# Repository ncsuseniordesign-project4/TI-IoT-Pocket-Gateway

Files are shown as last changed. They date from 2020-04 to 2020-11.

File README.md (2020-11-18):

# TI-IoT-Pocket-Gateway

Please see the [wiki](https://github.com/ncsuseniordesign-project4/TI-IoT-Pocket-Gateway/wiki) as well!

## Hardware

Hardware design files can be found under the `hardware` folder. You will need AutoCAD Eagle to modify these files.

CAM Data:
   The up to day CAM outputs are in the zipped file "IoT_Pocket_Gateway_Final.zip". 

## Software

Demo scripts, testing tools, etc can be found under the `software` folder, including a simple demo web app for communicating with a remote device using the Azure IoT Hub.

## Configuration

A `systemd` service for modem configuration / management can be found under the `configuration` folder. The various demo scripts in the `software` folder also provide examples showing how the buttons and LEDs can be used. Please see the [wiki](https://github.com/ncsuseniordesign-project4/TI-IoT-Pocket-Gateway/wiki) as well!

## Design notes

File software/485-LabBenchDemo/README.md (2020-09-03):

# TI-IoT-Pocket-Gateway

## Dependencies

* bonescript
* azure-iot-device
* azure-iot-device-mqtt

Dependencies can be installed via `npm install <dependency_name>`. Note that `bonescript` is install by default on the PocketBeagle and does not need to be reinstalled.

## Cloud9 IDE QuickStart
The PocketBeagle must have an exsiting network connection.

First, clone this repo to a new subfolder of `/var/lib/cloud9` on the PocketBeagle. Next, start up Cloud9 in your web browser. In the left hand Workspace view a new `TI-IoT-Pocket-Gateway` folder will now be present. Expand this folder as well as the 485-LabBenchDemo folder. The `485-LabBenchDemo.js` file will now be displayed and can be opened by double clicking it. This will open the source code in the IDE.

Now that the file is open switch to the Clound9 terminal. Ensure the project dependencies are installed (see the above dependencies section). Once the dependencies have been installed ensure your IoT Device primary key has been added to the configuration file at `/etc/485-LabBenchDemo.conf`. If no configuration file has yet been created a sample configuration, `485-LabBenchDemo.conf.sample`, has been provided which can be copied to `/etc/485-LabBenchDemo.conf`.

Once the configuration is correct the program can be started via Cloud9's "Run" button. Once started the program will print the messages it receives from Azure and handle defined method calls.

### Cloud9 Autostart

This program can be autostarted by Cloud9 by copying or symlinking it to the `/var/lib/cloud9/autorun` folder. An active network connection is not required to start the program and the program will automatically start sending messages to Azure once a network connection has been made.

## NPM and Node QuickStart
Run the following commands after cloning or after git pull.

First, go to the directory with all the scripts and the package.json file

To install the package dependencies, run the following command:

```
npm install
```

A folder called `node_modules` will be created with all the Azure dependencies

Now, edit `/etc/485-LabBenchDemo.conf` to provide the program with your IoT Device primary key. A sample config, `485-LabBenchDemo.conf.sample`, has been provided so the configuration file does not need to be created from scratch.

Run the script with node command:

```
node [script-of-your-choice].js
```

The data will be sent to the IoT device specified by the connectionString in JSON format.

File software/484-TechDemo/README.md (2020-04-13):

# TI-IoT-Pocket-Gateway

## Dependencies

* bonescript
* azure-iot-device
* azure-iot-device-mqtt

Dependencies can be installed via `npm install <dependency_name>`. Note that `bonescript` is install by default on the PocketBeagle and does not need to be reinstalled.

## Cloud9 IDE QuickStart
The PocketBeagle must have an exsiting network connection.

First, clone this repo to a new subfolder of `/var/lib/cloud9` on the PocketBeagle. Next, start up Cloud9 in your web browser. In the left hand Workspace view a new `TI-IoT-Pocket-Gateway` folder will now be present. Expand this folder as well as the 484-TechDemo folder. The `484-TechDemo.js` file will now be displayed and can be opend by double clicking it. This will open the source code in the IDE.

Now that the file is open switch to the Clound9 terminal. Ensure the project dependencies are installed (see the above dependencies section). Once the dependencies have been installed ensure your IoT Device primary key has been added to the configuration file at `/etc/484-TechDemo.conf`. If no configuration file has yet been created a sample configuration, `484-TechDemo.conf.sample`, has been provided which can be copied to `/etc/484-TechDemo.conf`.

Once the configuration is correct the program can be started via Cloud9's "Run" button. Once started the program will print the messages it sends to Azure to the log and the RGB LED will be controllable by moving the TechLab around.

### Cloud9 Autostart

This program can be autostarted by Cloud9 by copying or symlinking it to the `/var/lib/cloud9/autorun` folder. An active network connection is not required to start the program and the program will automatically start sending messages to Azure once a network connection has been made.

## NPM and Node QuickStart
Run the following commands after cloning or after git pull.

First, go to the directory with all the scripts and the package.json file

To install the package dependencies, run the following command:

```
npm install
```

A folder called `node_modules` will be created with all the Azure dependencies

Now, edit `/etc/484-TechDemo.conf` to provide the program with your IoT Device primary key. A sample config, `484-TechDemo.conf.sample`, has been provided so the configuration file does not need to be created from scratch.

Run the script with node command:

```
node [script-of-your-choice].js
```

The data will be sent to the IoT device specified by the connectionString in JSON format.

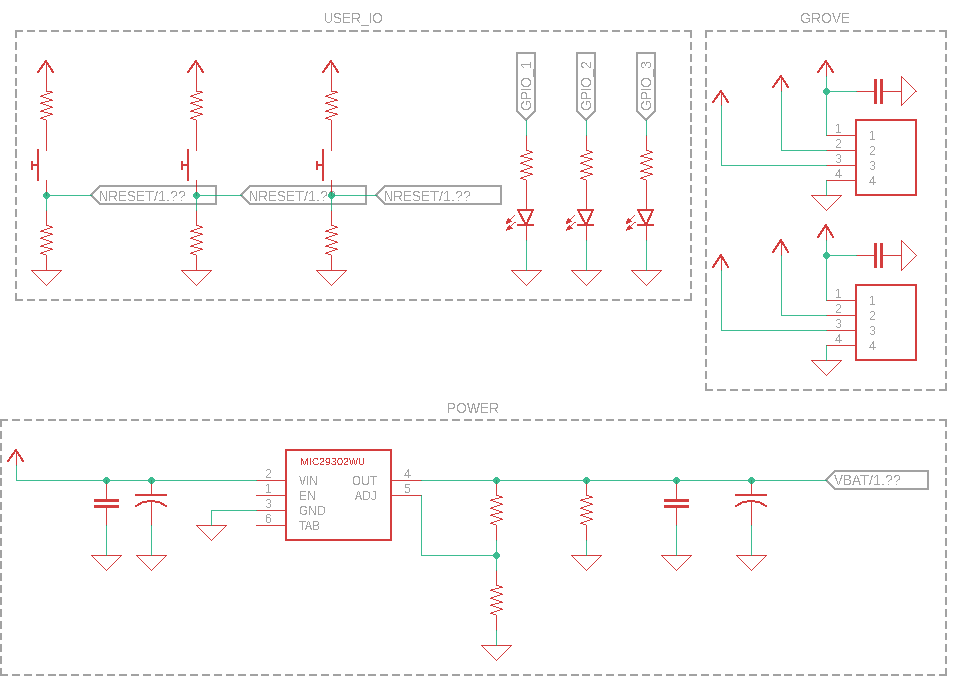
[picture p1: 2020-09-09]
hardware/Eagle/Sheet 2 Update.png

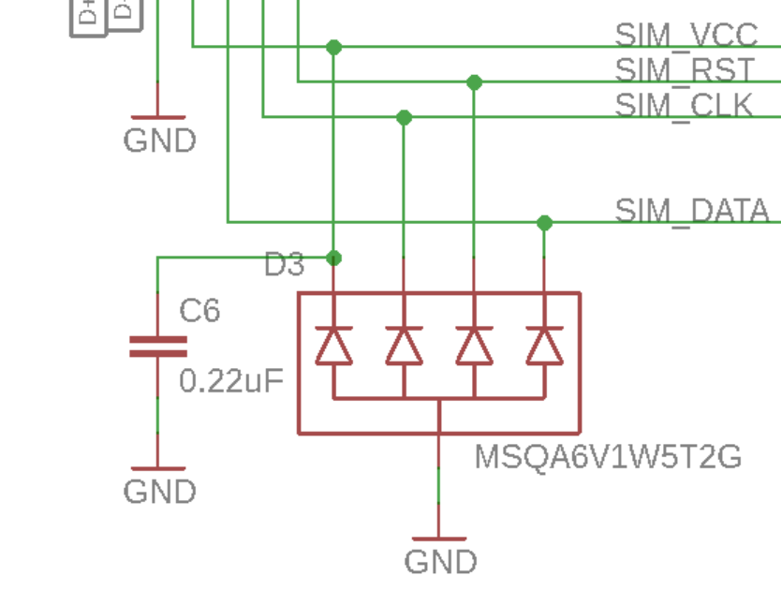
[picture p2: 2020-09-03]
hardware/Eagle/Sim 3.3v ESD diode.png

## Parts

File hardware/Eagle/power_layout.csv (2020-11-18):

Part | Value | Device | Package | Description | AVAILABILITY | BUILT_BY | CENTERLINE_PITCH | COMMENT | COPYRIGHT | DATASHEET | DESCRIPTION | DIGI-KEY_PART_NUMBER | DIGI-KEY_PURCHASE_URL | EU_ROHS_COMPLIANCE | MANUFACTURER | MANUFACTURER_PART_NUMBER | MF | MP | MPN | NUMBER_OF_POSITIONS | OC_FARNELL | OC_NEWARK | PACKAGE | POPULARITY | PRICE | PRODUCT_TYPE | PROD_ID | SOURCELIBRARY | SPICEPREFIX | TE_PURCHASE_URL | TP_SIGNAL_NAME | VALUE | VENDOR
BTN2 | PTS636SM25F | PTS636SM25F | SW2_PTS636_SM25F_SMTR_LFS_CNK
BTN3 | PTS636SM25F | PTS636SM25F | SW2_PTS636_SM25F_SMTR_LFS_CNK
C1 | 100uF | C-USC0805 | C0805 | CAPACITOR, American symbol |  |  |  |  |  |  |  |  |  |  |  |  |  |  |  |  |  |  |  | 63 |  |  |  |  | C
C2 | 0.1uF | C-USC0805 | C0805 | CAPACITOR, American symbol |  |  |  |  |  |  |  |  |  |  |  |  |  |  |  |  |  |  |  | 63 |  |  |  |  | C
C3 | 330uF | C-USC1210 | C1210 | CAPACITOR, American symbol |  |  |  |  |  |  |  |  |  |  |  |  |  |  |  |  |  |  |  | 6 |  |  |  |  | C
C4 | 1uF | C-USC0805 | C0805 | CAPACITOR, American symbol |  |  |  |  |  |  |  |  |  |  |  |  |  |  |  |  |  |  |  | 63 |  |  |  |  | C
C5 | 100nF | C-USC0805 | C0805 | CAPACITOR, American symbol |  |  |  |  |  |  |  |  |  |  |  |  |  |  |  |  |  |  |  | 63 |  |  |  |  | C
C6 | .1uF | C-USC0805 | C0805 | CAPACITOR, American symbol |  |  |  |  |  |  |  |  |  |  |  |  |  |  |  |  |  |  |  | 63 |  |  |  |  | C
C7 | 0.1uF | C-USC0805 | C0805 | CAPACITOR, American symbol |  |  |  |  |  |  |  |  |  |  |  |  |  |  |  |  |  |  |  | 63 |  |  |  |  | C
C8 | .1uF | C-USC0805 | C0805 | CAPACITOR, American symbol |  |  |  |  |  |  |  |  |  |  |  |  |  |  |  |  |  |  |  | 63 |  |  |  |  | C
C9 | .1uF | C-USC0805 | C0805 | CAPACITOR, American symbol |  |  |  |  |  |  |  |  |  |  |  |  |  |  |  |  |  |  |  | 63 |  |  |  |  | C
C10 | .1uF | C-USC0805 | C0805 | CAPACITOR, American symbol |  |  |  |  |  |  |  |  |  |  |  |  |  |  |  |  |  |  |  | 63 |  |  |  |  | C
C11 | .1uF | C-USC0805 | C0805 | CAPACITOR, American symbol |  |  |  |  |  |  |  |  |  |  |  |  |  |  |  |  |  |  |  | 63 |  |  |  |  | C
C12 | 27pF | C-USC0603 | C0603 | CAPACITOR, American symbol |  |  |  |  |  |  |  |  |  |  |  |  |  |  |  |  |  |  |  | 37 |  |  |  |  | C
C13 | 27pF | C-USC0603 | C0603 | CAPACITOR, American symbol |  |  |  |  |  |  |  |  |  |  |  |  |  |  |  |  |  |  |  | 37 |  |  |  |  | C
C14 | 27pF | C-USC0603 | C0603 | CAPACITOR, American symbol |  |  |  |  |  |  |  |  |  |  |  |  |  |  |  |  |  |  |  | 37 |  |  |  |  | C
C15 | 27pF | C-USC0603 | C0603 | CAPACITOR, American symbol |  |  |  |  |  |  |  |  |  |  |  |  |  |  |  |  |  |  |  | 37 |  |  |  |  | C
C16 | 33pF | C-EUC0603K | C0603K | CAPACITOR, European symbol |  |  |  |  |  |  |  |  |  |  |  |  |  |  |  |  |  |  |  | 30 |  |  |  |  | C
C17 | 3uF | C-USC0805 | C0805 | CAPACITOR, American symbol |  |  |  |  |  |  |  |  |  |  |  |  |  |  |  |  |  |  |  | 63 |  |  |  |  | C
CR1 | 9C-6.000MAAJ-T | 9C-6.000MAAJ-T | CRYSTAL_TXC_9C_TXC |  |  | EMA_UL_Team |  |  |  |  |  |  |  |  |  | 9C-6.000MAAJ-T |  |  |  |  |  |  |  |  |  |  |  | TXC_2011-01-01_CRYSTAL_9C |  |  |  |  | TXC
CR2 | ESDA6V1-5SC6SOT23-6L_STM-M | ESDA6V1-5SC6SOT23-6L_STM-M | SOT23-6L_STM-M |  |  | EMA_UL_Team |  |  |  |  |  |  |  |  |  | ESDA6V1-5SC6 |  |  |  |  |  |  |  |  |  |  |  | Update_database_2020-10-15 |  |  |  |  | STMicroelectronics
D1 | RED | LED-RED1206 | LED-1206 | Red SMD LED |  |  |  |  |  |  |  |  |  |  |  |  |  |  |  |  |  |  |  |  |  |  | DIO-09912 |  |  |  |  | RED
D2 | GREEN | LED-GREEN1206 | LED-1206 | Green SMD LED |  |  |  |  |  |  |  |  |  |  |  |  |  |  |  |  |  |  |  |  |  |  | DIO-00862 |  |  |  |  | GREEN
D3 | BLUE | LED-BLUE1206 | LED-1206 | Blue SMD LED |  |  |  |  |  |  |  |  |  |  |  |  |  |  |  |  |  |  |  |  |  |  | DIO-09911 |  |  |  |  | BLUE
D4 | Yellow | LED-YELLOW0603 | LED-0603 | Yellow SMD LED |  |  |  |  |  |  |  |  |  |  |  |  |  |  |  |  |  |  |  |  |  |  | DIO-09003 |  |  |  |  | Yellow
D5 | Yellow | LED-YELLOW0603 | LED-0603 | Yellow SMD LED |  |  |  |  |  |  |  |  |  |  |  |  |  |  |  |  |  |  |  |  |  |  | DIO-09003 |  |  |  |  | Yellow
GROVE1 | 640456-4 | 640456-4 | TE_640456-4 | 220P MTA100 HDR ASSY SQ SPCL |  |  | 2.54 mm[.1 in] | 640456-4 |  |  | Header, Friction Lock | MTA-100 | 4 | 250 VAC | Polyester | Tin | Copper Alloy | Tin | A1922-ND | https://www.digikey.com/product-detail/en/te-connectivity-amp-connectors/640456-4/A1922-ND/109006 | Compliant |  |  | TE Connectivity | 640456-4 |  | 4 |  |  | None |  |  | Connector
GROVE2 | 640456-4 | 640456-4 | TE_640456-4 | 220P MTA100 HDR ASSY SQ SPCL |  |  | 2.54 mm[.1 in] | 640456-4 |  |  | Header, Friction Lock | MTA-100 | 4 | 250 VAC | Polyester | Tin | Copper Alloy | Tin | A1922-ND | https://www.digikey.com/product-detail/en/te-connectivity-amp-connectors/640456-4/A1922-ND/109006 | Compliant |  |  | TE Connectivity | 640456-4 |  | 4 |  |  | None |  |  | Connector
J1 | AU-Y1008-2 | AU-Y1008-2 | CONN_AU-Y1008-2_ASM |  |  | EMA_Cory |  |  | Copyright (C) 2018 Accelerated Designs. All rights reserved | http://www.assmann-wsw.com/fileadmin/datasheets/ASS_5780_CO.pdf |  |  |  |  |  | AU-Y1008-2 |  |  |  |  |  |  |  |  |  |  |  | Assmann_2020-03-30 |  |  |  |  | Assmann
J2 | U.FL-R-SMT-1(01) | U.FL-R-SMT-1(01) | CONN_-SMT-1(01) |  |  | EMA_Matt |  |  | Copyright (C) 2018 Accelerated Designs. All rights reserved |  |  |  |  |  |  | U.FL-R-SMT-1(01) |  |  |  |  |  |  |  |  |  |  |  | Hirose_12_20_2019 |  |  |  |  | Hirose
J3 | U.FL-R-SMT-1(01) | U.FL-R-SMT-1(01) | CONN_-SMT-1(01) |  |  | EMA_Matt |  |  | Copyright (C) 2018 Accelerated Designs. All rights reserved |  |  |  |  |  |  | U.FL-R-SMT-1(01) |  |  |  |  |  |  |  |  |  |  |  | Hirose_12_20_2019 |  |  |  |  | Hirose
JP1 |  | PINHD-1X2 | 1X02 | PIN HEADER |  |  |  |  |  |  |  |  |  |  |  |  |  |  |  |  |  |  |  | 98
JP2 |  | PINHD-1X2 | 1X02 | PIN HEADER |  |  |  |  |  |  |  |  |  |  |  |  |  |  |  |  |  |  |  | 98
JP3 |  | PINHD-1X1 | 1X01 | PIN HEADER |  |  |  |  |  |  |  |  |  |  |  |  |  |  |  |  |  |  |  | 64
JP4 |  | PINHD-1X1 | 1X01 | PIN HEADER |  |  |  |  |  |  |  |  |  |  |  |  |  |  |  |  |  |  |  | 64
JP5 |  | PINHD-1X1 | 1X01 | PIN HEADER |  |  |  |  |  |  |  |  |  |  |  |  |  |  |  |  |  |  |  | 64
JP6 |  | PINHD-1X2 | 1X02 | PIN HEADER |  |  |  |  |  |  |  |  |  |  |  |  |  |  |  |  |  |  |  | 98
JP7 |  | PINHD-1X2 | 1X02 | PIN HEADER |  |  |  |  |  |  |  |  |  |  |  |  |  |  |  |  |  |  |  | 98
JP8 |  | PINHD-1X2 | 1X02 | PIN HEADER |  |  |  |  |  |  |  |  |  |  |  |  |  |  |  |  |  |  |  | 98
JP9 |  | PINHD-1X1 | 1X01 | PIN HEADER |  |  |  |  |  |  |  |  |  |  |  |  |  |  |  |  |  |  |  | 64
JP10 |  | PINHD-1X1 | 1X01 | PIN HEADER |  |  |  |  |  |  |  |  |  |  |  |  |  |  |  |  |  |  |  | 64
L1 | 47nH | C-EUC1608 | C1608 | CAPACITOR, European symbol |  |  |  |  |  |  |  |  |  |  |  |  |  |  |  |  |  |  |  | 3 |  |  |  |  | C
POWER_SUPPLY | MIC29302WU | MIC29302WU | TO263-5 |  | Unavailable |  |  |  |  |  | Linear Voltage Regulator IC 1 Output 3A TO-263-5 |  |  |  |  |  | Microchip Technology | MIC29302WU |  |  |  |  | TO-263-6 Microchip Technology |  | None
R1 | 60.4 | RESISTOR0805 | 0805 | Generic Resistor Package
R2 | 180 | RESISTOR0805 | 0805 | Generic Resistor Package
R3 | 180 | RESISTOR0805 | 0805 | Generic Resistor Package
R4 | 47k | RESISTOR0805 | 0805 | Generic Resistor Package
R5 | 100k | RESISTOR0805 | 0805 | Generic Resistor Package
R6 | 470k | RESISTOR0805 | 0805 | Generic Resistor Package
R7 | 27 | RESISTOR0805 | 0805 | Generic Resistor Package
R8 | 27 | RESISTOR0805 | 0805 | Generic Resistor Package
R9 | 1.5k | 1KOHM-0603-1/10W-1% | 0603 | 1kΩ resistor |  |  |  |  |  |  |  |  |  |  |  |  |  |  |  |  |  |  |  |  |  |  | RES-07856 |  |  |  |  | 1k
R10 | 4700 | RESISTOR0805 | 0805 | Generic Resistor Package
R11 | 47k | 47KOHM-0603-1/10W-1% | 0603 | 47kΩ resistor |  |  |  |  |  |  |  |  |  |  |  |  |  |  |  |  |  |  |  |  |  |  | RES-07871 |  |  |  |  | 47k
R13 | 15k | RESISTOR0805 | 0805 | Generic Resistor Package
R14 | 4700 | RESISTOR0805 | 0805 | Generic Resistor Package
R15 | 15k | RESISTOR0805 | 0805 | Generic Resistor Package
R16 | 4700 | RESISTOR0805 | 0805 | Generic Resistor Package
R17 | 4.7k | 4.7KOHM-0603-1/10W-1% | 0603 | 4.7kΩ resistor |  |  |  |  |  |  |  |  |  |  |  |  |  |  |  |  |  |  |  |  |  |  | RES-07857 |  |  |  |  | 4.7k
R18 | 47k | 47KOHM-0603-1/10W-1% | 0603 | 47kΩ resistor |  |  |  |  |  |  |  |  |  |  |  |  |  |  |  |  |  |  |  |  |  |  | RES-07871 |  |  |  |  | 47k
R19 | 27 | RESISTOR0805 | 0805 | Generic Resistor Package
R20 | 27 | RESISTOR0805 | 0805 | Generic Resistor Package
R21 | 27 | RESISTOR0805 | 0805 | Generic Resistor Package
R22 | 27 | RESISTOR0805 | 0805 | Generic Resistor Package
R23 | 15k | RESISTOR0805 | 0805 | Generic Resistor Package
R24 | 15k | RESISTOR0805 | 0805 | Generic Resistor Package
R25 | 1.5k | RESISTOR0805 | 0805 | Generic Resistor Package
R26 | 0 | 1KOHM-0603-1/10W-1% | 0603 | 1kΩ resistor |  |  |  |  |  |  |  |  |  |  |  |  |  |  |  |  |  |  |  |  |  |  | RES-07856 |  |  |  |  | 1k
R27 | 0 | 1KOHM-0603-1/10W-1% | 0603 | 1kΩ resistor |  |  |  |  |  |  |  |  |  |  |  |  |  |  |  |  |  |  |  |  |  |  | RES-07856 |  |  |  |  | 1k
R28 | 330 | 1KOHM-0603-1/10W-1% | 0603 | 1kΩ resistor |  |  |  |  |  |  |  |  |  |  |  |  |  |  |  |  |  |  |  |  |  |  | RES-07856 |  |  |  |  | 1k
R29 | 4700 | RESISTOR0805 | 0805 | Generic Resistor Package
R30 | 4700 | RESISTOR0805 | 0805 | Generic Resistor Package
R31 | 4700 | RESISTOR0805 | 0805 | Generic Resistor Package
R32 | 4700 | RESISTOR0805 | 0805 | Generic Resistor Package
R33 | 330 | 1KOHM-0603-1/10W-1% | 0603 | 1kΩ resistor |  |  |  |  |  |  |  |  |  |  |  |  |  |  |  |  |  |  |  |  |  |  | RES-07856 |  |  |  |  | 1k
R34 | 15k | RESISTOR0805 | 0805 | Generic Resistor Package
R35 | 15k | RESISTOR0805 | 0805 | Generic Resistor Package
R36 | 15k | RESISTOR0805 | 0805 | Generic Resistor Package
R37 | 15k | RESISTOR0805 | 0805 | Generic Resistor Package
R38 | 45k | RESISTOR0805 | 0805 | Generic Resistor Package
R39 | 10 | RESISTOR0805 | 0805 | Generic Resistor Package
RESET | PTS636SM25F | PTS636SM25F | SW2_PTS636_SM25F_SMTR_LFS_CNK
SIMCARD | 78646-3001 | 78646-3001 | MOLEX_78646-3001 | Conn Micro SIM Card SKT 6 POS 2.54mm Solder RA SMD 0.5A/Contact Embossed T/R | Unavailable |  |  |  |  |  | 6 Position Card Connector Micro SIM Surface Mount, Right Angle Gold |  |  |  |  |  | Molex | 78646-3001 |  |  |  |  | None |  | None
SV1 |  | MA18-2 | MA18-2 | PIN HEADER |  |  |  |  |  |  |  |  |  |  |  |  |  |  |  |  | unknown | unknown |  | 0
SV2 |  | MA18-2 | MA18-2 | PIN HEADER |  |  |  |  |  |  |  |  |  |  |  |  |  |  |  |  | unknown | unknown |  | 0
T1 | BCX70SMD | BCX70SMD | SOT23 | NPN TRANSISTOR |  |  |  |  |  |  |  |  |  |  |  |  |  |  |  |  |  |  |  | 0
T2 | BCX70SMD | BCX70SMD | SOT23 | NPN TRANSISTOR |  |  |  |  |  |  |  |  |  |  |  |  |  |  |  |  |  |  |  | 0
TP1 | TPTP10R | TPTP10R | TP10R | Test pad |  |  |  |  |  |  |  |  |  |  |  |  |  |  |  |  |  |  |  | 3
TP2 | TPTP16R | TPTP16R | TP16R | Test pad |  |  |  |  |  |  |  |  |  |  |  |  |  |  |  |  |  |  |  | 0
TP3 | TPTP10R | TPTP10R | TP10R | Test pad |  |  |  |  |  |  |  |  |  |  |  |  |  |  |  |  |  |  |  | 3
TP4 | TPTP10R | TPTP10R | TP10R | Test pad |  |  |  |  |  |  |  |  |  |  |  |  |  |  |  |  |  |  |  | 3
TP5 | TPTP10R | TPTP10R | TP10R | Test pad |  |  |  |  |  |  |  |  |  |  |  |  |  |  |  |  |  |  |  | 3
TP6 | TPTP10R | TPTP10R | TP10R | Test pad |  |  |  |  |  |  |  |  |  |  |  |  |  |  |  |  |  |  |  | 3
TP7 | TPTP10R | TPTP10R | TP10R | Test pad |  |  |  |  |  |  |  |  |  |  |  |  |  |  |  |  |  |  |  | 3
TP8 | TPTP10R | TPTP10R | TP10R | Test pad |  |  |  |  |  |  |  |  |  |  |  |  |  |  |  |  |  |  |  | 3
TP21 | TPTP10R | TPTP10R | TP10R | Test pad |  |  |  |  |  |  |  |  |  |  |  |  |  |  |  |  |  |  |  | 3
TP22 | TPTP10R | TPTP10R | TP10R | Test pad |  |  |  |  |  |  |  |  |  |  |  |  |  |  |  |  |  |  |  | 3
TP26 | TPTP10R | TPTP10R | TP10R | Test pad |  |  |  |  |  |  |  |  |  |  |  |  |  |  |  |  |  |  |  | 3
TP27 | TPTP10R | TPTP10R | TP10R | Test pad |  |  |  |  |  |  |  |  |  |  |  |  |  |  |  |  |  |  |  | 3
TP28 | TPTP10R | TPTP10R | TP10R | Test pad |  |  |  |  |  |  |  |  |  |  |  |  |  |  |  |  |  |  |  | 3
U1 | SIM7000E | SIM7000E | SIMCON_SIM7000E | Multi-Band LTE-FDD and Dual-Band GSM/GPRS/EDGE module solution in a SMT type which supports LTE eMTC(CAT-M1) and NB-IoT up to 375kbps for downlink data transfer. | Unavailable |  |  |  |  |  | SIM7000E GSM/GPRS RF Arduino Platform Evaluation Expansion Board |  |  |  |  |  | DFRobot | SIM7000E |  |  |  |  | Package Analog Devices |  | None
U2 | TUSB2046BVFR | TUSB2046BVFR | VF32_TEX |  |  | EMA_UL_Team |  |  | Copyright (C) 2018 Accelerated Designs. All rights reserved |  |  |  |  |  | Texas Instruments | TUSB2046BVFR |  |  |  |  |  |  |  |  |  |  |  | Texas_Instruments_2018-12-15 |  |  |  |  | Texas Instruments
U3 | MAX3373EEKA+T | MAX3373EEKA+T | 21-0078H |  |  | EMA_UL_Team |  |  |  |  |  |  |  |  |  | max3373eeka+t |  |  |  |  |  |  |  |  |  |  |  | Maxim_2009-12-17_3a |  |  |  |  | Maxim Integrated Products
U4 | TPS2044BDR | TPS2044BDR | D16_TEX |  |  | EMA_UL_Team |  |  |  |  |  |  |  |  | Texas Instruments | TPS2044BDR |  |  |  |  |  |  |  |  |  |  |  | TI_2014-06-19 |  |  |  |  | Texas Instruments
X1 | 332-04 | 332-04 | 332-04 | 4 Pin - 2mm Dual Row |  |  |  |  |  |  |  |  |  |  |  |  |  |  |  |  |  |  |  | 0

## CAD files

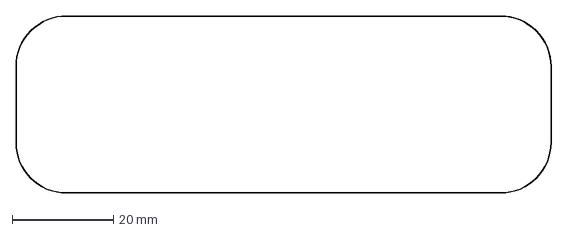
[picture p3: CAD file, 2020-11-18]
hardware/Eagle/Board Edge.dxf
105.8 x 35.0 mm

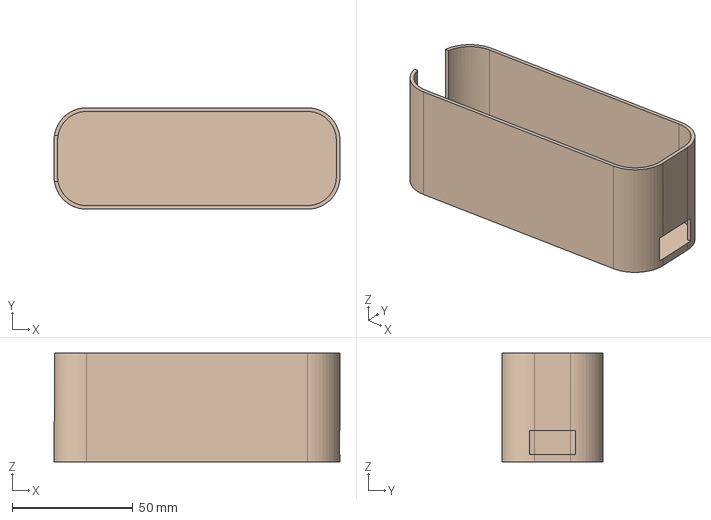
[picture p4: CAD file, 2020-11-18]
hardware/enclosure/Body Bottom v10.step
118.4 x 42.0 x 45.0 mm

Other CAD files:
hardware/enclosure/Body Bottom v11.stl
hardware/enclosure/Body Bottom v11.f3d

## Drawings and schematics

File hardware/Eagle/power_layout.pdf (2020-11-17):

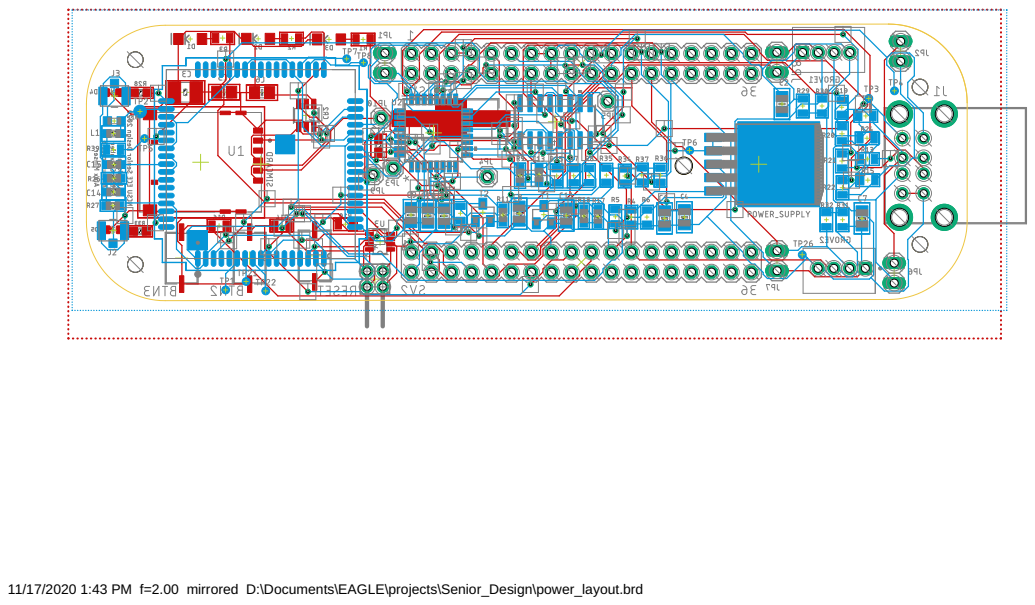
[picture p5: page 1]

11/17/2020 1:43 PM f=2.00 mirrored D:\Documents\EAGLE\projects\Senior_Design\power_layout.brd

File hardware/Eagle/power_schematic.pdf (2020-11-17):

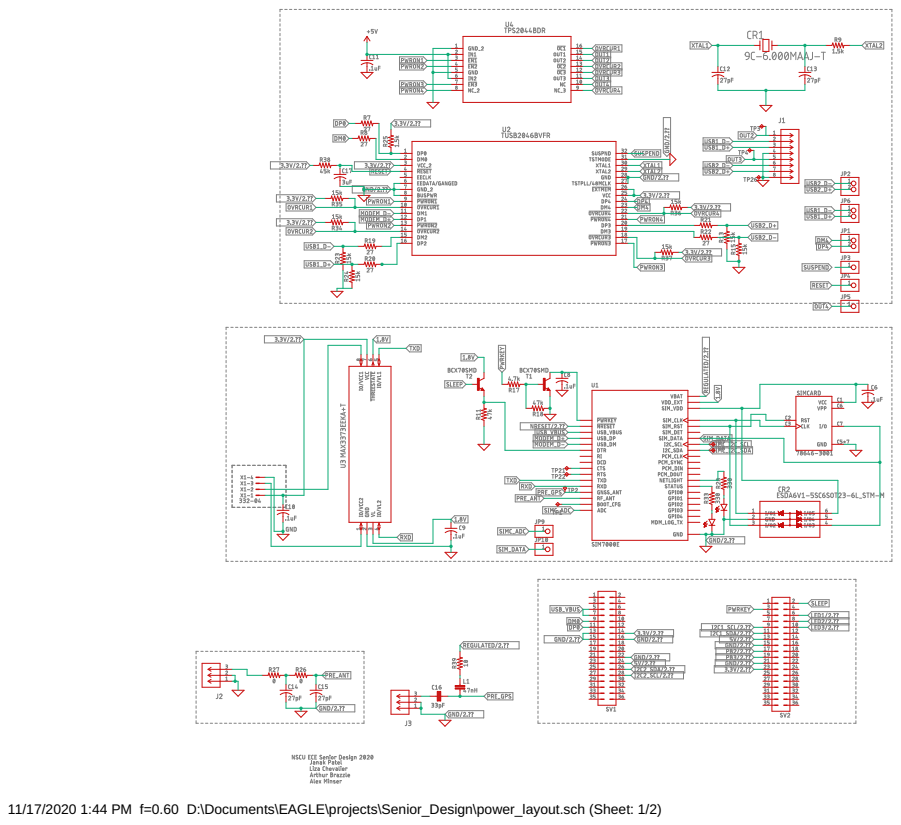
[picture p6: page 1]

11/17/2020 1:44 PM f=0.60 D:\Documents\EAGLE\projects\Senior_Design\power_layout.sch (Sheet: 1/2)

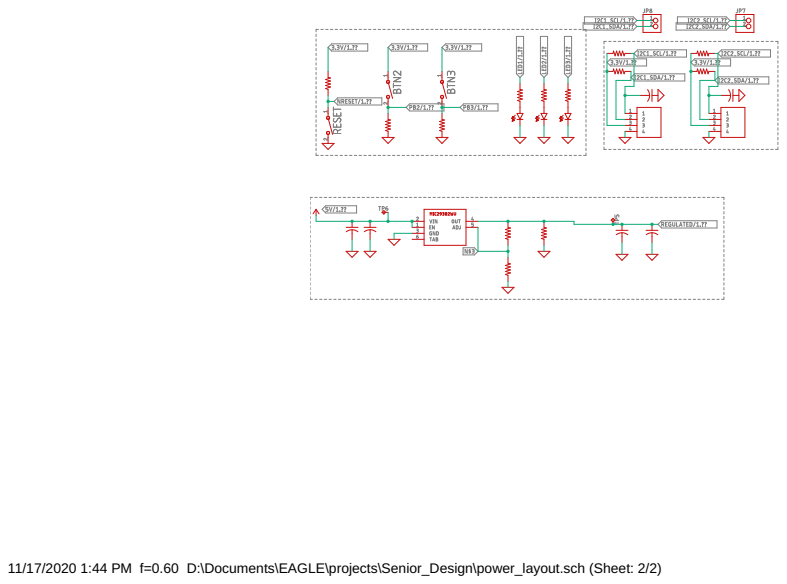
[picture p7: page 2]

11/17/2020 1:44 PM f=0.60 D:\Documents\EAGLE\projects\Senior_Design\power_layout.sch (Sheet: 2/2)

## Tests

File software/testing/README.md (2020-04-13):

# TI-IoT-Pocket-Gateway

Run the following commands after cloning or after git pull

First, go to the directory with all the scripts and the package.json file

To install the package dependencies, run the following command

          npm install

A folder called node_modules will be created with all the azure api code

Now, edit the one of the scripts and add your IoT Device primary key to the connectionString variable
Save the script.

Run the script with node command.

          node [script-of-your-choice].js
 
The data will be sent to the IoT device specified by the connectionString in JSON format

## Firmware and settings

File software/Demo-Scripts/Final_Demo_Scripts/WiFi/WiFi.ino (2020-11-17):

/**
 * The following script simulates a water pump which turns the LED (connected on pin 19) 
 * on or off when the respective command is received from the MQTT broker.
 * 
 * TI IoT Pocket Gateway Team at NC State University (ECE 484/485 - Senior Design - 2020)
 * 
 * Author: Janak Patel
 * 
 * The following code is a modified version of the script written by Rui Santos from 
 * randomnerdtutorials.com. The original version can be found on the below link
 * https://randomnerdtutorials.com/esp32-mqtt-publish-subscribe-arduino-ide/
 */

#include <WiFi.h>
#include <PubSubClient.h>
#include "Esp32MQTTClient.h"

// Please input the SSID and password of WiFi
const char* ssid     = ""; /*WiFi name here*/
const char* password = ""; /*WiFi password here*/
const int   redLEDPin = 19;
const char* mqtt_server = "";  /*Ip address of the broker*/

WiFiClient espClient;
PubSubClient client(espClient);

void setup() {
  Serial.begin(115200);
  Serial.println("Starting connecting WiFi.");
  delay(10);
  WiFi.begin(ssid, password);
  while (WiFi.status() != WL_CONNECTED) {
    delay(500);
    Serial.print(".");
  }
  Serial.println("WiFi connected");
  Serial.println("IP address: ");
  Serial.println(WiFi.localIP());
  delay(50);
  client.setServer(mqtt_server, 1883);  /* Set the MQTT server */
  client.setCallback(callback);
  pinMode(redLEDPin, OUTPUT);
  digitalWrite(redLEDPin, LOW);
}

void callback(char* topic, byte* message, unsigned int length) {
  Serial.print("Message arrived on topic: ");
  Serial.print(topic);
  Serial.print(". Message: ");
  String tempMessage;
  
  for (int i = 0; i < length; i++) {
    Serial.print((char)message[i]);
    tempMessage += ((char)message[i]);
  }
  Serial.println();

  if (tempMessage == "ON"){
    Serial.println("Turning ON the water pump");
    digitalWrite(redLEDPin, HIGH);
    client.publish("Cloud", "{\"client\":\"ESP32\", \"message\":\"Successfully turned on the water pump\"}");
  }
  else if (tempMessage == "OFF"){
    Serial.println("Turning OFF the water pump");
    digitalWrite(redLEDPin, LOW);
    client.publish("Cloud", "{\"client\":\"ESP32\", \"message\":\"Successfully turned off the water pump\"}");
  }
  else {
    Serial.println("Unknown command received");
    client.publish("Cloud", "{\"client\":\"ESP32\", \"message\":\"Received an unknown command! No changes made\"}");
  }
  
}

void reconnect() {
  digitalWrite(redLEDPin, LOW);
  // Loop until we're reconnected
  while (!client.connected()) {
    Serial.print("Attempting MQTT connection...");
    // Attempt to connect
    if (client.connect("ESP32")) {
      Serial.println("connected");
      // Subscribe
      client.subscribe("ESP32");
    } else {
      Serial.print("failed, rc=");
      Serial.print(client.state());
      Serial.println(" try again in 5 seconds");
      // Wait 5 seconds before retrying
      delay(5000);
    }
  }
}

void loop() {
  
  if (!client.connected()) {
    reconnect();
  }
  client.loop();
}

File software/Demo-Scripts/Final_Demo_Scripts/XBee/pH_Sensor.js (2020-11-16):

/**
 * This following code simulates a pH sensor in an IoT network and sending data using XBee module 
 * via serial port.
 * 
 * TI IoT Pocket Gateway team at NC State University (ECE 484/485 - Senior Design)
 * 
 * @author Janak Patel
 */


var xbee_api = require('xbee-api');
var C = xbee_api.constants;
var SerialPort = require('serialport');
var receiverMacAddr = "";   // mac address of the XBee module to which the data needs to be sent
const InterByteTimeout = require('@serialport/parser-inter-byte-timeout');

// xbeeApi object creation
var xbeeAPI = new xbee_api.XBeeAPI({
    api_mode: 1,              // [1, 2]; 1 is default, 2 is with escaping (set ATAP=2)
    parser_buffer_size: 512,  // (int); size of the package parser buffer. 512 co
                              //   when receiving A LOT of packets, you might want to decrease 
                              //   this to a smaller value (but typically not less than 128)
    builder_buffer_size: 512  // (int); size of the package builder buffer. 
                              //   when sending A LOT of packets, you might want to decrease
                              //   this to a smaller value (but typically not less than 128)
});

// open a serial port connection with specified baud rate
var serialport = new SerialPort('/dev/ttyUSB0', {
    baudRate: 115200
});

// set the serial port parser
// The parser waits for 100 ms of silence after some data is received
// and then triggers the callback to ensure all the data is received 
// before parsing it.
const parser = serialport.pipe(new InterByteTimeout({interval: 100}));

// callback method for serial port error
serialport.on('error', function(err) {
    console.log('Error: ', err.message)
});

// callback method triggered when the parser received the complete message
parser.on('data', function (data) {
    
	try{
        var parsed = xbeeAPI.parseFrame(data);          // parse the raw data 
        
        // extract the actual message as a string and disregard the zigbee header data
        var parsedStringData = parsed.data.toString();  

        var jsonMsg = JSON.parse(parsedStringData);     // convert the string message to JSON format

        console.log("Received Command from ", jsonMsg.client, " :", jsonMsg.message);   // log the data to console

        // if the ph data was requested
        if (jsonMsg.message == "request_PH_data"){
            
            // generate a random ph reading between 6.00 and 7.00
            var phReading = 6.0 + (Math.floor(Math.random() * 100))/100;

            // construct the return message for the requesting device
            var message = {
                client: "XBee",
                topic: jsonMsg.client,
                message: "pH reading: " + phReading.toString()
            }

            var frame_obj = {
                type: C.FRAME_TYPE.ZIGBEE_TRANSMIT_REQUEST, // xbee_api.constants.FRAME_TYPE.ZIGBEE_TRANSMIT_REQUEST
                destination64: receiverMacAddr,
                data: JSON.stringify(message)// Can either be string or byte array.
            };
            
            // write the message to serial port to send it
            serialport.write(xbeeAPI.buildFrame(frame_obj), function(){
                serialport.drain();
            });

            console.log ("Message Sent: ", message);    // log the message
        }
        else{
            console.log("Unknown Command Received");    // if any other command was received
        }
	}
	catch(e){
        // do nothing
	}
});

// callback method triggered when the serial port is opened successfully
serialport.on('open', function(){
    console.log("pH Sensor Ready"); // log the message to show the system is now ready
});

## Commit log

2020-04-02 Added eagle stuff
    [power_layout.brd, power_layout.sch]
2020-04-04 Update README.md
    PCB Design
    Change Notes:
    -4/4/2020 11AM: Added pocketbeagle pinout to document with library. I will modify it but the part can hang out as a reference.
    Work to do:
    -Voltage Regulator: I think we need a SOT-23 form factor chip for size reasons. The current one may still fit though.
    -SMD pin fooprint: I need to convert the pocketBeagle(PB) pins to an SMD .1" pin header for the bottom side connection to the PB.
    -SIM Card Diodes: We should replace the diodes with the packaged diode array in the reference schematic. It is a SOT-23 package.
    -Buttons: We should tranisiton to smaller form factor buttons.
2020-04-04 Arthur's 1st Push
    Annotated on Readme as 4/4/2020 11AM push
    [PocketBeagle.brd, PocketBeagle.sch, power_layout.brd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]
2020-04-09 Schematic & Layout Updates
    Updates made prior to poster publishing for Demo Day Poster!
    [Board Edge.dxf, power_layout.brd, power_layout.sch]
2020-04-13 Add config and LED support
    This commit adds configuration support to the program so that the source
    code does not need to be edited to change the IoT Device primary key or
    the time delay between program loop iterations. This makes it easier to
    use the program in multiple environments and removes the risk of
    accidentally committing secret keys to the repository.
    RGB LED support has also been added to the program. Now any data read
    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
2020-09-03 Add 485 Lab Bench Demo
    Adds ECE 485 Lab Bench Demo code. The Lab Bench Demo allows a user to
    control the green and blue channels of the RGB LED on the TechLab cape
    remotely via Azure. It also provides a way for the user to remotely
    query IP information.
2020-09-09 PCB Review 2 meeting Push
    [power_layout.brd, power_layout.sch, power_layout_SLIM.brd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]
2020-09-10 Hopefully Final Changes Pre-Alpha Purchase
    *Still need to generate GERBERS*
    [power_layout.brd, power_layout.sch]
2020-09-11 Added team names to pcb and created gerber files
    [power_layout.brd, power_layout.sch]
2020-09-11 Fixed issues w/ gerber files
    [DRILEGEND.CFG, power_layout.brd, power_layout.sch]
2020-09-14 Alpha Order Design Changes
    Incorporated all PCB Review design changes
    [power_layout.brd, power_layout.sch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]
2020-09-14 Updated C3 Size and regenerated CAM
    Part swap pre-ordering
    [power_layout.brd, power_layout.sch]
2020-09-14 Updating missing part values
    Alex had assigned these before but I wrote over them on accident :)
    [power_layout.brd, power_layout.sch]
2020-10-19 Beta Boar Spin Files
    Implemented board revisions from Alpha board.
    [gerber_job.gbrjob, power_layout.GBL, power_layout.GBO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]
2020-10-19 Beta Board Spin Upload
    Implemented Alpha Board Changes.
    Cleaned up folder to remove old CAM outputs
    [copper_bottom.gbr, copper_top.gbr, drill_1_16.xln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]
2020-10-21 Add files via upload
    This push includes the changes from Dr Pitts' Review and is THE Beta Board for purchasing.
    -Cam files are processed in the folder "Beta Spin"
    [gerber_job.gbrjob, power_layout.GBL, power_layout.GBO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]
2020-11-16 added button script and the main gateway script used in the final demo.
2020-11-16 modified the package.json for the pocketbeagle node.js script. Added the XBee ph sensor scripts
2020-11-17 Adding Final Design Files
    Incorporated all changes from Beta Assembly
    [power_layout.brd, power_layout.csv, power_layout.sch]
2020-11-17 added Ethernet and WiFi final demo scripts. Removed sensitive data from the broker script.
    [WiFi.ino, brokerToCloud.js]
2020-11-17 Adding PDF's of schematic and layout
2020-11-17 Uploading Enclosure Design Files and .stl for 3D printing
    [Body Bottom v10.step, Body Bottom v11.f3d, Body Bottom v11.stl]
2020-11-18 Reorganize repo for project conclusion
    Concludes the NCSU senior design work for the TI IoT Pocket Gateway.
    Repository has been reorganized for better navigation and cleaned up to
    remove old files.
    [Board Edge.dxf, Body Bottom v10.step, Body Bottom v11.f3d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]
